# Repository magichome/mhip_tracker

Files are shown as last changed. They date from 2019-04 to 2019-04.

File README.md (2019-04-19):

# mhip_tracker

## Introduction

With my interest in IoT, the Internet-of-Things, I decided to create a device to addresses a use case I have, asset tracking.  Specifically I wanted a self-contained, solar powered GPS Tracker that periodically reports position to a cloud data store.  Primarily I'll use this to track by travels (I travel a lot in an RV).

This project will cover all aspects of the tracker device including hardware, software, packaging, and data visualization.

### Parts Used

- [Particle.io Boron](https://docs.particle.io/datasheets/cellular/boron-datasheet/)
  - An Arduino compatible controller with cellular connectivity.
- [Adafruit GPS FeatherWing](https://www.adafruit.com/product/3133)
  - -165 dBm sensitivity, 10 Hz updates, 66 channels with internal patch antenna
- [Adafruit Temperature/Humidity Sensor](https://www.adafruit.com/product/393)
  - wired DHT22 sensor in a plastic housing
- [Voltaic USB Battery Pack](https://www.voltaicsystems.com/v44)
  - Model V44, 12,000mAh / 44 Watt hour
- [Voltaic Solar Panel](https://www.voltaicsystems.com/9-watt-panel)
  - 9 watts, 6 volts, plugs directly into the V44 battery pack.
- Component case and solar panel mount
  - Custom 3D printed
- Double-sided tape, grommets, bolts and nuts

### Services Used

- [Particle.io Cloud](https://www.particle.io/)
- Microsoft Azure
  - [IOT Hub](https://azure.microsoft.com/en-us/services/iot-hub/)
  - [Event Grid](https://azure.microsoft.com/en-us/services/event-grid/)
  - [Table Storage](https://azure.microsoft.com/en-us/services/storage/tables/)

### Discussion

The "brains" of Tracker is the particle.io Boron controller board.  The Boron is Arduino compatible and in the Adafruit Feather [formfactor](https://learn.adafruit.com/adafruit-feather/feather-specification). In addition to the controller it has a cellular modem that communicates with the cellular network.  Depending on the model you choose, it can use either G2/G3 or LTE.  I chose G3 since it gives greater coverage compares to LTE.

The Boron includes a SIM that you activate with the particle.io mobile app running on either an [Android](https://play.google.com/store/apps/details?id=io.particle.android.app&hl=en_US) or the [iPhone](https://itunes.apple.com/us/app/particle-iot/id991459054).  Out of the box, Boron communicates with the particle.io cloud (at the time of this writing the particle.io cloud is free for the first three months then $2.99 per month per device).  With their cloud subscription you get 3MB of data per month. Additional megabytes start at $0.40/MB.  In addition to activating your Boron, the mobile app can be used to monitor and control your devices.

In addition to cellular connectivity, the particle.io devices can communicate with each other via a mesh network.  I plan to use the capability in future IoT projects to combine location data with other sensor data I collect.

The particle.io cloud is more than just a data hub for their products.  It is a centralized place to manage your devices as well as a Web IDE for writing and flashing code to your devices.

I've taken a couple stabs at creating an IoT controller with cellular connectivity.  This included a roll-my-own attempt using a RaspberryPi and the AT&T IoT developer board.  Those didn't work out.  I had run across particle.io but, at that time, their devices weren't ready.  Time passed before my latest attempt so I revisited their offerings.  It looked promising so I decided to give it a try.  I'm impressed.  Not only do they have good hardware, they're created an ecosystem around the hardware that makes IoT development easy.  Yes, easy.  I had my Boron registered and reporting status to the particle.io cloud within minutes of powering it up.  I breadboarded it with the GPS module, wrote some code with their [Web IDE][1], flashed it to the device (also through the Web IDE), and had it reporting location within just a couple hours.

Since the Boron is compatible with the Adafruit Feather specification, I looked (on [adafruit.com](https://adafruit.com) naturally) for a compatible GPS module.  I chose the [Adafruit GPS FeatherWing](https://www.adafruit.com/product/3133) because of its easy serial connectivity and integrated antenna.

The temperature/humidity sensor was added because, well, why not?  Temperature and humidity are interesting things to know, right?

Since I want the Tracker to be standalone, I needed to supply power.  Solar is an  obvious part of the solution.  The Boron has an integral charge controller and LiPo battery.  You could hook a solar panel to the Boron USB connection to power the device and charge the LiPo.  When there isn't enough solar, the LiPo can power the device.

Having dealt with solar powered devices for some time, I knew that powering the device this way would be problematic.  Solar panels rarely live up to their claimed power output in real world situations.  Dust accumulation on the panel, low sun angle, shade, clouds, all contribute to the challenge.  Since I intended to attach this to a vehicle, I can't optimize the angle of the panel or ensure that it will always be in locations with adequate sunlight[2][2].  My approach was to get the largest solar panel I could coupled with a hefty battery pack.  The large solar panel can charge the battery pack as quickly as possible and the battery pack can keep the device running for days without sun.  The [Voltaic USB Battery Pack](https://www.voltaicsystems.com/v44) I chose has a couple desirable features that are important for this application:

- The solar panel plugs directly into the battery pack.  The panel can charge the battery even while it's providing power to the device.  Many battery packs can't do this.
- Always on.  If the battery pack is fully drained, it will start providing power to the connected device as soon as an adequate level of charge is attained.
- Weatherproof

With all of the parts selected, I needed a way to package them.  Since Tracker will be exposed to the weather, the case needed some level of weather and UV resistance.  Since its going to be attached to a vehicle, it will encounter wind forces and foreign object impacts.  Specifically I was going to need a box to house the controller, GPS module and battery pack. I would also need a mount for the solar panel.  I couldn't find anything off the shelf.  Fortunately this need intersected with my growing interest in 3D printing.  And it provided the needed justification to buy a 3D printer!

[1]: If you're not a fan of Web IDE's, particle has a workbench extension for Visual Code so you can develop and compile locally.  See the [Software Section](doc/software.md) for more information.

[2]: Using solar power on vehicles, e.g. an RV, is challenging in itself.  The desire to keep the vehicle out of the sun to protect it (and keep it cool in the summer), is diametrically opposed to the needs of solar power.

### More Information

- [Hardware](doc/hardware.md)
- [Software](doc/software.md)
- [3D Printed Parts](doc/cad.md)
- Data Processing (coming...)
- Performance (coming...)

### Images

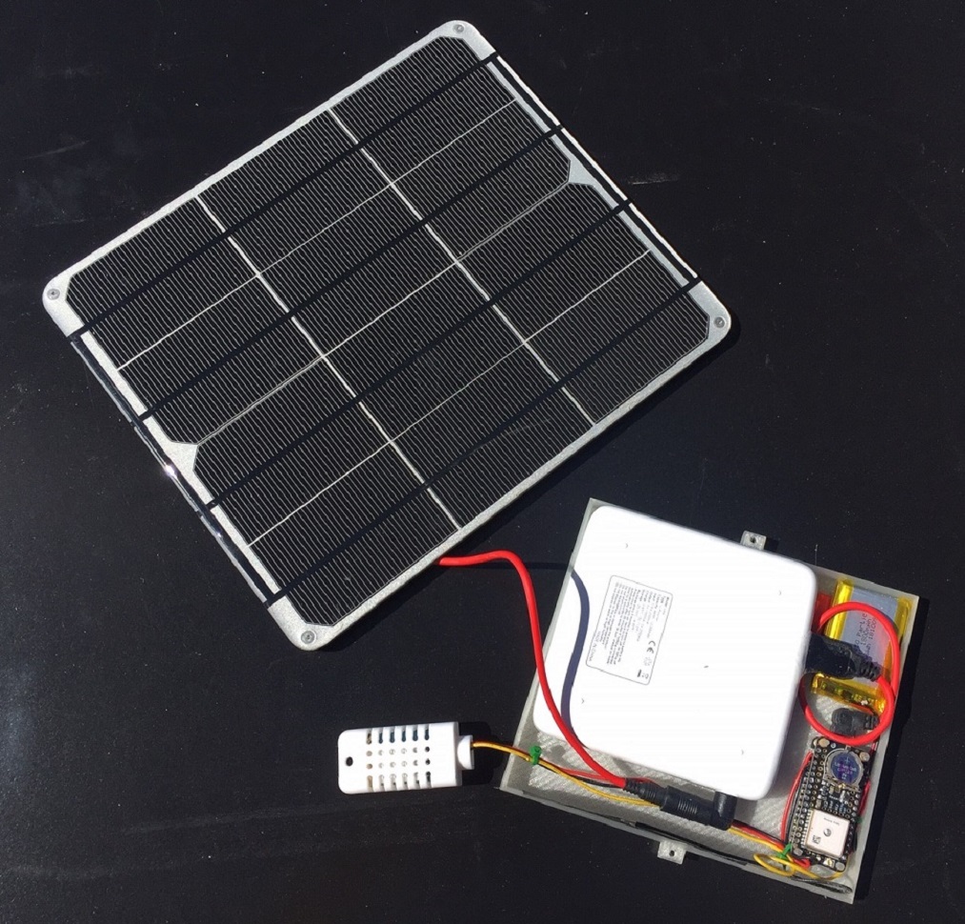
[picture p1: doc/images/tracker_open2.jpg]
Tracker Open View 2

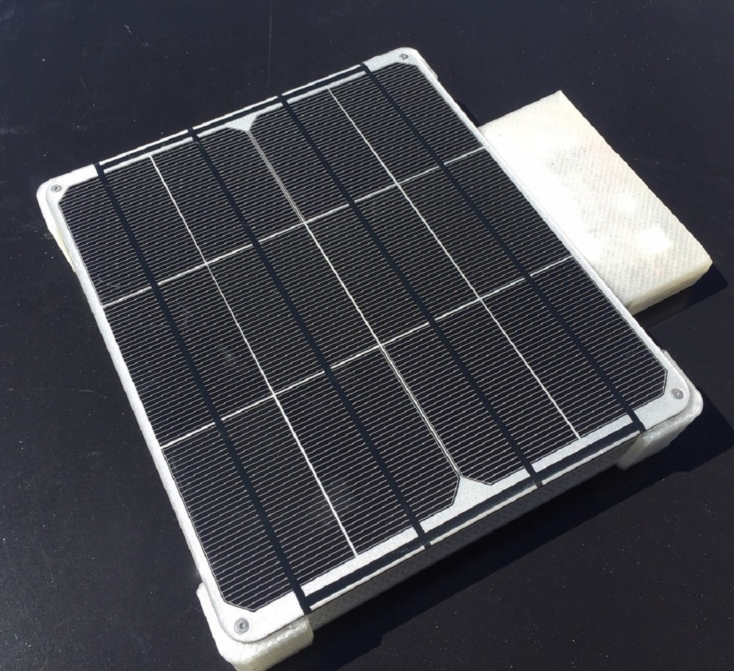
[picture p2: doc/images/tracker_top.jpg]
Tracker Top

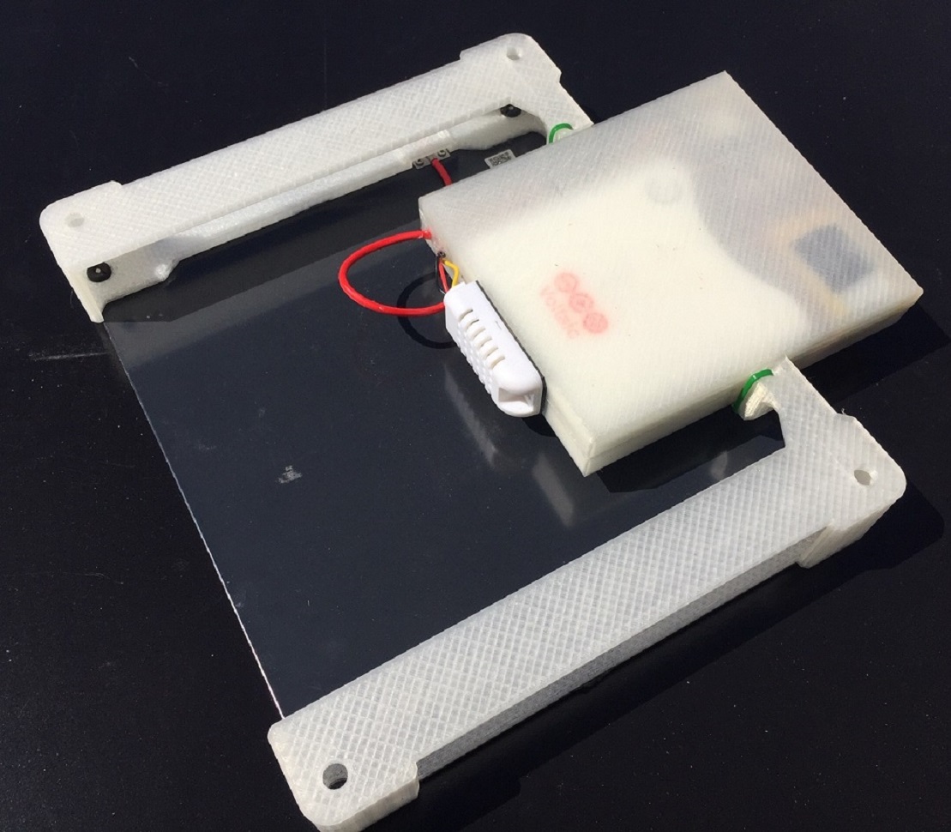
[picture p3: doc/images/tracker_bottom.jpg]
Tracker Bottom


### Note

I am not affiliated with any company or product mentioned in this project.  All products and services were chosen based on my own research and paid for my me.

### Licenses

Source Code: [MIT](https://opensource.org/licenses/MIT)

Text and Images: [Creative Commons Attribution-ShareAlike 3.0 Unported](https://creativecommons.org/licenses/by-sa/3.0/legalcode)

**Copyright 2019, MagicHome Inc., All rights reserved.**

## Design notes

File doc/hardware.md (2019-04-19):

# mhip_tracker : Hardware

## Parts Used

- [Particle.io Boron](https://docs.particle.io/datasheets/cellular/boron-datasheet/)
  - An Arduino compatible controller with cellular connectivity.

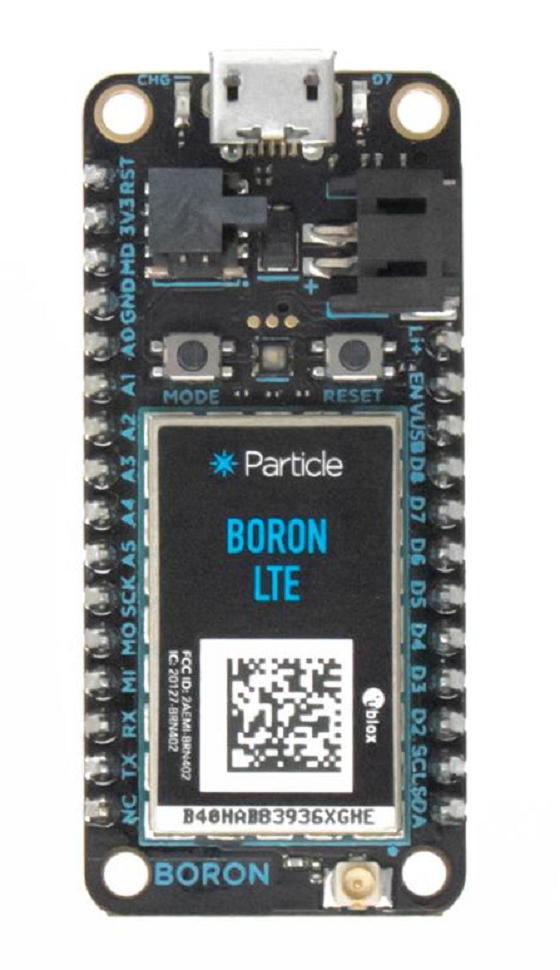
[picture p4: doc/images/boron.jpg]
particle.io Boron controller
    

- [Adafruit GPS FeatherWing](https://www.adafruit.com/product/3133)
  - -165 dBm sensitivity, 10 Hz updates, 66 channels with internal patch antenna

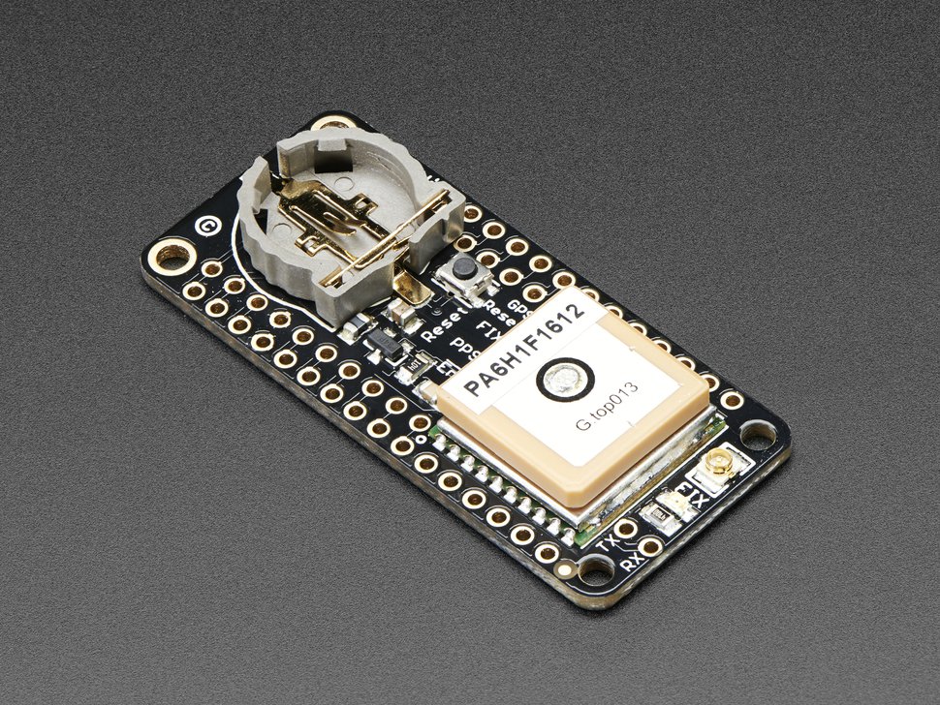
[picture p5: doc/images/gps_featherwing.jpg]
Adafruit GPS FeatherWing
    

- [Adafruit Temperature/Humidity Sensor](https://www.adafruit.com/product/393)
  - wired DHT22 sensor in a plastic housing

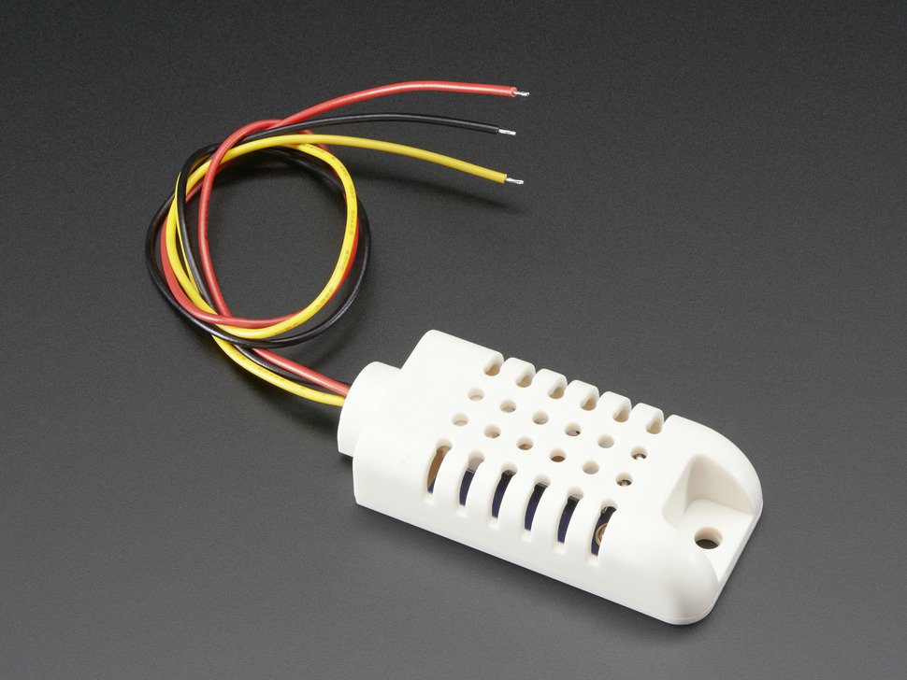
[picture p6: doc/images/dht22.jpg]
Adafruit Temperature and Humidity Sensor
    

- [Voltaic USB Battery Pack](https://www.voltaicsystems.com/v44)
  - Model V44, 12,000mAh / 44 Watt hour

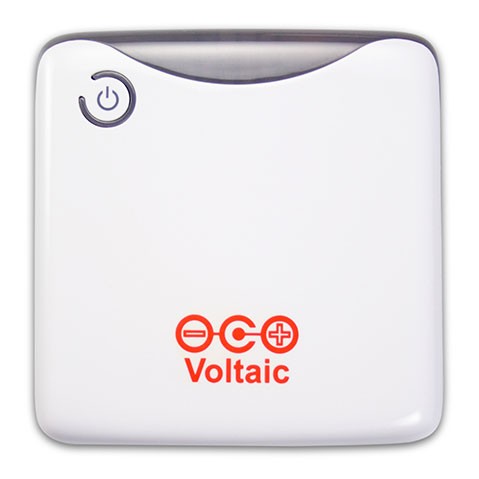
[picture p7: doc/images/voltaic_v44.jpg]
Voltaic V44 Battery Pack
    

- [Voltaic Solar Panel](https://www.voltaicsystems.com/9-watt-panel)
  - 9 watts, 6 volts, plugs directly into the V44 battery pack.

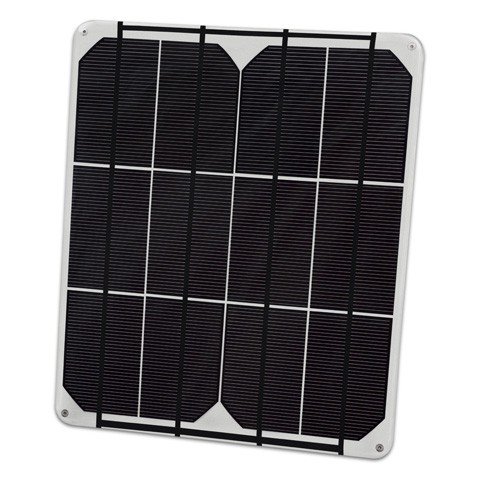
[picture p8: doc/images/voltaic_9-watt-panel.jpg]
Voltaic 9W Solar Panel
    

_todo: fritzing diagram, assembly_

**Copyright 2019, MagicHome Inc., All rights reserved.**

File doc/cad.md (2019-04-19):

# mhip_tracker : 3D Printed Parts

## Case and Solar Panel Mount

The ```cad``` folder has [SketchUp](https://www.sketchup.com/) and .STL files for the case (top and bottom) and solar panel mount.  These can be used to 3D print these components.

## Design Considerations

Packaging requirements:

- External mount
  - For solar power
  - Good gps singal reception
  - Good cellular connectivity.
- Self-contained
  - All of the parts together in a single package.

These requirements present several design considerations.  Since tracker is outside and moving with a vehicle, it is subject to hazards such as...

- Heat, rain, hail
- UV radiation
- Foreign object impact; e.g. rocks, tree limbs

Heat, rain, hail and UV radiation can be mitigated somewhat by keeping things shaded.  The solar panel cannot be shaded (obviously) but it is designed with the hazards in mind.  I can used the solar panel for shade it positioned off the vehicle enough.  Keep in mind though that solar panels get HOT.  So there would need to be good airflow around it so it doesn't transfer heat to the things it's shading.

Foreign object impacts are mitigated by keeping things as low profile as possible and designing them strong enough to handle incidental impacts.

## About the printer

I used the [Qidi X-Plus](http://www.qd3dprinter.com/products/x-plus/) printer.  I selected this printer based on reviews and max print size.  It has been very easy to use and reliable.  The slicing software seems a little less than smooth but it gets the job done.  The components are printed with generic PLA filament.  I chose translucent so I could see flashing lights on the components (for troubleshooting) without disassembly.

## Components

### Case

The case houses the Voltaic battery pack, the LiPo battery included with Boron, the Boron controller and the GPS board.  The battery pack being the largest of these.  I positioned the GPS board on top of the Boron so it's internal antenna would have an unobstructed view of the sky.  I positioned these toward one edge so I could position that side of the box exposed while the rest of the case could be in the shade under the solar panel.

### Solar Panel Mounts

These were designed to hold the panel up high enough to provide shade for the case.  In addition, they are somewhat minimal and open to improve airflow.  Finally, they fall along the short dimension of the panel to make them small enought to print in my 3D printer.

## Lessons Learned

Originally I had intended to mount the component case and solar panels separately.  I also intended to use heavy-duty double-sided tape to hold them to the vehicle.  I had already printed the cases with this in mind but quickly discovered the following...

_The box tabs are too small._

The tabs are too small to hold the case halves together.  For a "version 2" I would probably make these 2x larger and have four tabs, one along each side.

I also discovered that...

_The box warps as it cools, it won't lay flat._

This is a 3D printing thing for large, flat surfaces.  I think if I let it cool an the build platform it may stay flat.  In any case this means that using double-side tape to secure the case to the vehicle would be compromised since the contact surface area is reduced.

So while designing the solar mount brackets, I wanted to incorporate a way to tie the case to the brackets.  This would give a little extra force to keep it attached to the vehicle.

_The bracket "openings" for the box tabs are too tight._

3D print plastic expands a little during printing making holes and other clearances tighter than designed.  I allowed for this and it mostly worked out.  However, in this complex tab recepticle, it wasn't enough.  I took one shot at fixing the problem but still not enough.  The brackets take a long time to print so instead of fixing the design I just used a dremel tool to open them up a bit.

_It's probably a good idea to get the nuts, bolts, and screws you intend to use before designing._

I sized holes according to screws and bolts I assumed I could readily find.  I couldn't.  That's why I went with plastic pins on the circuit boards and cable ties for the case tabs.  I think the approach I took turned out fine but I would have designed things a little differently if I knew this ahead of time.

_The case should probably be rotated 90 degrees counterclockwise so both batteries would be shaded by the solar panel._

Oooh, better idea.  Rotate the case _45 degrees_ counterclockwise!  That way only the corner with the GPS antenna needs to be outside the shade of the solar panel.  In addition the distance between the case and the solar panel mounts is reduced making for a more robust connection.  Finally, having the case angled to the vehicle motion would reduce the force of foreign object impacts.

## Closing Remarks

I've already printed all of the components I need for my application so I won't be spending any time right now to improve them.  If anyone would like to make improvements or offer alternative packaging and mounting designs, just give me a pull request.

**Copyright 2019, MagicHome Inc., All rights reserved.**

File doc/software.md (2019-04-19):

# mhip_tracker : Software

The particle.io Boron is an Arduino controller and programmed similarly.  The quickest and easiest way to program your Boron is via the particle.io Web IDE.  Once you register your device and create an account on particle.io, you will be able to navigate to the online [console](https://console.particle.io) where you can access your device, write code, and flash your device.  Simply copy the content of the src/mhip_tracker.ino file into the Web IDE.  Buttons on the left margin of the IDE let you compile and flash your device.

Alternatively you can use [Visual Code](https://code.visualstudio.com/) editor with the [Particle Workbench](https://www.particle.io/workbench/) extension.  If you don't already have Visual Code installed, the Particle Workbench link will give you the opportunity to install it with the extension pre-installed.  Otherwise, if you do have Visual Code, you can install the extension via the Visual Code marketplace.

Note that this code was written and tested on deviceOS 0.9.0.

(The information below is generic particle.io development documentation.)

## Development

Particle projects are composed of 3 important elements:

### ```/src``` folder:

This is the source folder that contains the firmware files for your project. It should *not* be renamed. 
Anything that is in this folder when you compile your project will be sent to our compile service and compiled into a firmware binary for the Particle device that you have targeted.

If your application contains multiple files, they should all be included in the `src` folder. If your firmware depends on Particle libraries, those dependencies are specified in the `project.properties` file referenced below.

### ```.ino``` file:

This file is the firmware that will run as the primary application on your Particle device. It contains a `setup()` and `loop()` function, and can be written in Wiring or C/C++. For more information about using the Particle firmware API to create firmware for your Particle device, refer to the [Firmware Reference](https://docs.particle.io/reference/firmware/) section of the Particle documentation.

### ```project.properties``` file:

This is the file that specifies the name and version number of the libraries that your project depends on. Dependencies are added automatically to your `project.properties` file when you add a library to a project using the `particle library add` command in the CLI or add a library in the Desktop IDE.

## Adding additional files to your project

### Projects with multiple sources

If you would like add additional files to your application, they should be added to the `/src` folder. All files in the `/src` folder will be sent to the Particle Cloud to produce a compiled binary.

### Projects with external libraries

If your project includes a library that has not been registered in the Particle libraries system, you should create a new folder named `/lib/<libraryname>/src` under `/<project dir>` and add the `.h`, `.cpp` & `library.properties` files for your library there. Read the [Firmware Libraries guide](https://docs.particle.io/guide/tools-and-features/libraries/) for more details on how to develop libraries. Note that all contents of the `/lib` folder and subfolders will also be sent to the Cloud for compilation.

## Compiling your project

When you're ready to compile your project, make sure you have the correct Particle device target selected and run `particle compile <platform>` in the CLI or click the Compile button in the Desktop IDE. The following files in your project folder will be sent to the compile service:

- Everything in the `/src` folder, including your `.ino` application file
- The `project.properties` file for your project
- Any libraries stored under `lib/<libraryname>/src`

**Copyright 2019, MagicHome Inc., All rights reserved.**

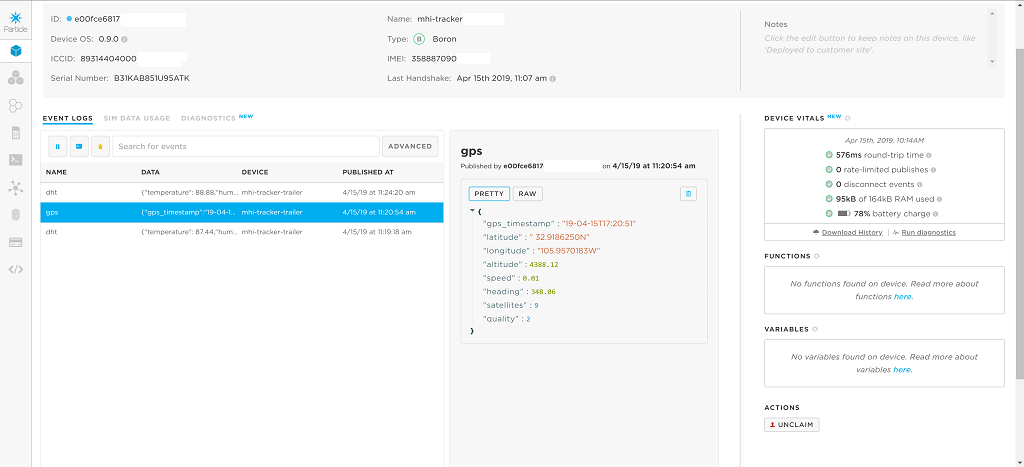
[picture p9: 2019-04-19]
doc/images/mhi_tracker_gps.png

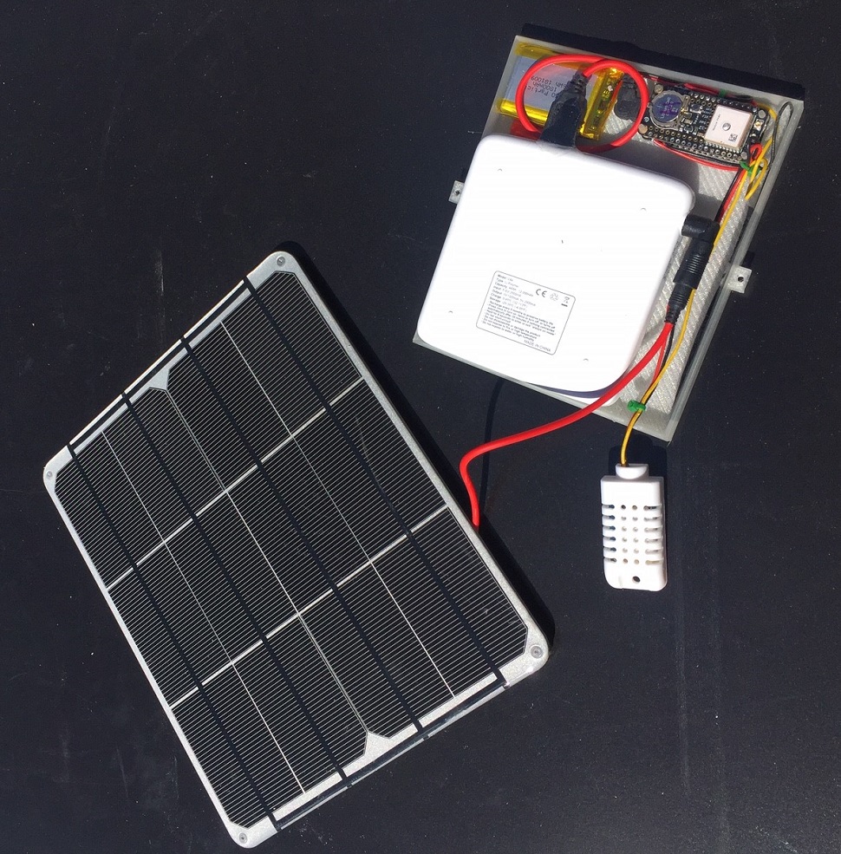
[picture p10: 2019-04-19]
doc/images/tracker_open1.jpg

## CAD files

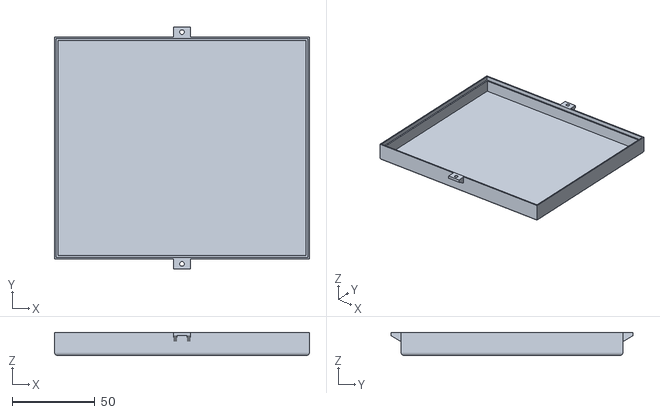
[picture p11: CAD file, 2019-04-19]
cad/miota_tracker_case_top.stl
154.0 x 146.0 x 14.0

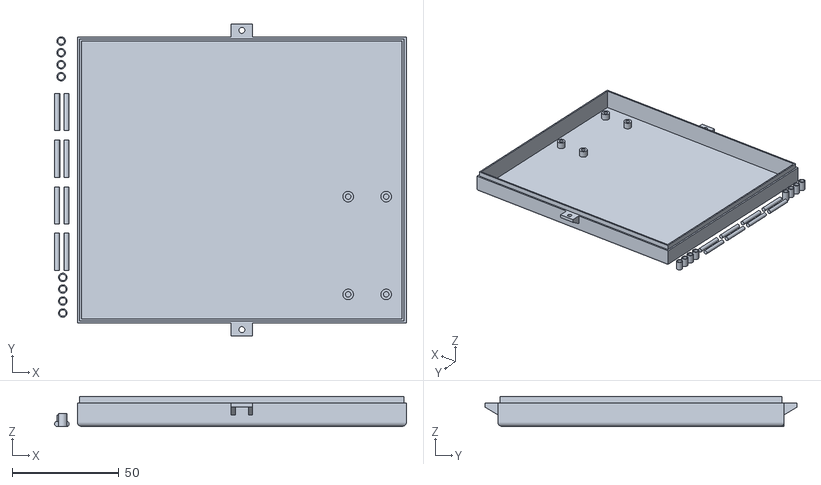
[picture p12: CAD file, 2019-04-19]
cad/miota_tracker_case_bottom.stl
164.7 x 146.0 x 14.1

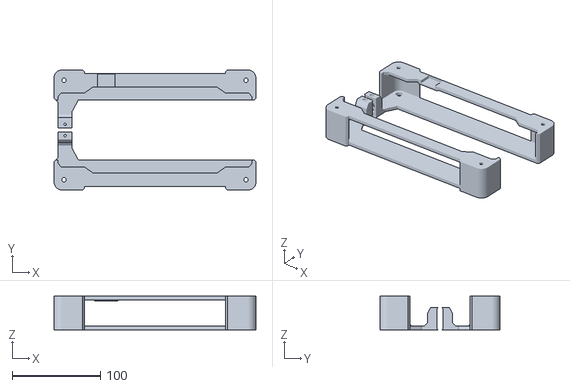
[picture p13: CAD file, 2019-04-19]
cad/miota_tracker_solar_mount.stl
229.1 x 136.2 x 38.0

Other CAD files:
cad/miota_tracker_case_bottom.skp
cad/miota_tracker_case_top.skp
cad/miota_tracker_solar_mount.skp

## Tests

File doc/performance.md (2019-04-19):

# mhip_tracker : Performance

## Batteries

- With fully charged batteries, tracker worked for 5+ days without charging.  
- Once the batteries were depleted, tracker started working again after x hours in decent sunlight.

## GPS

- Outstanding.

## DHT

- Temperature goes rogue occassionally.  When it's right, it's pretty accurate.  But sometimes it gives a reading about 50% higher than actual.  I'm attempting to do some validation on the temperature readings and only report those that seem accurate but the algorithm needs more work.

## Celluar Connectivity

- TBD

## Cost

### Components

### Services

**Copyright 2019, MagicHome Inc., All rights reserved.**

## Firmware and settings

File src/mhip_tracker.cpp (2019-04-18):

#include "application.h"
#line 1 "c:/Users/timjf/workspace/miota/mhip_tracker/src/mhip_tracker.ino"
/*
 * Project:     mhip_tracker
 * Description: GPS tracker using 2G/3G communication.
 * Author:      Timothy Fleming, MagicHome Inc
 * Date:        2019-03-24
 * Copyright:   MIT (see: https://opensource.org/licenses/MIT)
 */

#include <Adafruit_GPS.h>
#include <Adafruit_DHT.h>

void setupGPS();
void loopGPS();
int32_t calcCloudUpdateInterval(int32_t speed);
void setupDHT();
void loopDHT();
boolean validateTempurature(float t, float h);
void setup();
void loop();
#line 12 "c:/Users/timjf/workspace/miota/mhip_tracker/src/mhip_tracker.ino"
#define DHTPIN 3     // Digital pin connected to the DHT sensor 

// Uncomment the type of sensor in use:
//#define DHTTYPE    DHT11     // DHT 11
#define DHTTYPE    DHT22     // DHT 22 (AM2302)
//#define DHTTYPE    DHT21     // DHT 21 (AM2301)

// See guide for details on sensor wiring and usage:
//   https://learn.adafruit.com/dht/overview
DHT dht(DHTPIN, DHTTYPE);

// what's the name of the hardware serial port?
#define GPSSerial Serial1

// Connect to the GPS on the hardware port
Adafruit_GPS GPS(&GPSSerial);

// these are the intervals for when events get sent
// GPS cloud interval varies depending on speed; faster -> more frequent updates
uint32_t TI_GPS_CLOUD_MIN = 20 * 60 * 1000;   // 20 min, interval when we're stationary
uint32_t TI_GPS_CLOUD_MAX =  1 * 60 * 1000;   //  1 min, interval when we're moving fast
uint32_t TI_DHT_CLOUD     = 10 * 60 * 1000;   // 10 min
// MESH updates are all the same.  Sensors are read at this rate.
uint32_t TI_ALL_MESH      = 2000;             //  2 sec

// these are appended to the device name to create event names
#define EVENT_NAME_LOCATION "gps"
#define EVENT_NAME_TEMP "dht"

// init timer counts
uint32_t timer_gps_cloud = TI_GPS_CLOUD_MIN;
uint32_t timer_dht_cloud = TI_DHT_CLOUD;
uint32_t timer_mesh = 1000;

// these are used to apply some quality control to temp values
float t_last;
uint16_t t_count;

// message buffers
char msg_gps [250];
char msg_dht [120];

// ============================================================================
// GPS : Location Functions 
// ============================================================================

// Configure GPS board
void setupGPS() {
  Serial.println("GPS : setup");

  // This defines a variable with the particle cloud.  It enables us to query the value any time.
  Particle.variable("gps", msg_gps, STRING);

  // Note: the following code/comments are pasted from the Adafruit example code.  I don't actually know this
  // much about the GPS module.

  // 9600 NMEA is the default baud rate for Adafruit MTK GPS's- some use 4800
  GPS.begin(9600);
  // uncomment this line to turn on RMC (recommended minimum) and GGA (fix data) including altitude
  GPS.sendCommand(PMTK_SET_NMEA_OUTPUT_RMCGGA);
  // uncomment this line to turn on only the "minimum recommended" data
  //GPS.sendCommand(PMTK_SET_NMEA_OUTPUT_RMCONLY);
  // For parsing data, we don't suggest using anything but either RMC only or RMC+GGA since
  // the parser doesn't care about other sentences at this time
  // Set the update rate
  GPS.sendCommand(PMTK_SET_NMEA_UPDATE_1HZ); // 1 Hz update rate
  // For the parsing code to work nicely and have time to sort thru the data, and
  // print it out we don't suggest using anything higher than 1 Hz

  // Request updates on antenna status, comment out to keep quiet
  GPS.sendCommand(PGCMD_ANTENNA);

  delay(1000);

  // Ask for firmware version
  GPSSerial.println(PMTK_Q_RELEASE);
}

// GPS processing in main loop
void loopGPS() {
  // location formatting
  int32_t lat_units = GPS.latitude_fixed / 10000000;
  int32_t lat_decimal = GPS.latitude_fixed - (lat_units * 10000000);

  int32_t lon_units = GPS.longitude_fixed / 10000000;
  int32_t lon_decimal = GPS.longitude_fixed - (lon_units * 10000000);

  // unit conversions
  float speed_mph = GPS.speed * 1.15078;
  float alt_ft = GPS.altitude * 3.28084;

  // Format GPS message as json
  // Example: {"gps_timestamp":"19-03-26T20:04:33","latitude":" 39.7766033N","longitude":"105.1291466W","altitude": 5416.01,"speed":  0.17,"heading":257.14,"satellites":11,"quality":2}
  snprintf(msg_gps, 250, "{\"gps_timestamp\":\"%u-%02u-%02uT%02u:%02u:%02u\",\"latitude\":\"%3lu.%7lu%c\",\"longitude\":\"%3lu.%7lu%c\",\"altitude\":%8.2f,\"speed\":%6.2f,\"heading\":%6.2f,\"satellites\":%u,\"quality\":%u}", \
    GPS.year, GPS.month, GPS.day, GPS.hour, GPS.minute, GPS.seconds, \
    lat_units, lat_decimal, GPS.lat, \
    lon_units, lon_decimal, GPS.lon, \
    alt_ft, speed_mph, GPS.angle, GPS.satellites, GPS.fixquality);

  // output to console
  Serial.print("GPS: "); Serial.print(msg_gps);

  // mesh publish
  Mesh.publish(EVENT_NAME_LOCATION, msg_gps);

  // particle.io cloud publish, cloud interval is longer than mesh interval
  uint32_t dynamic_timer_interval = calcCloudUpdateInterval(speed_mph);
  if (millis() - timer_gps_cloud > dynamic_timer_interval) {
    timer_gps_cloud = millis(); // reset the timer
    Serial.print("*"); // give indication on console value that this one was published to cloud
    Particle.publish(EVENT_NAME_LOCATION, msg_gps, PRIVATE);
  }
  Serial.println("");
}

// The cloud update interval varies depending on speed.  Calculate the desired interval given the current speed.
int32_t calcCloudUpdateInterval(int32_t speed) 
{
  int32_t result = TI_GPS_CLOUD_MIN;

  if ( speed > 60 )
  {
    result = TI_GPS_CLOUD_MAX;
  } 
  else if ( speed > 2 )
  {
    result = (60 / speed) * TI_GPS_CLOUD_MAX;
  }

  return result;
}


// ============================================================================
// DHT : Temperature / Humidity Functions 
// ============================================================================

// Configure DHT temp/humidity sensor
void setupDHT() {
  // Initialize device.
  Serial.println("DHT : setup");

  // This defines a variable with the particle cloud.  It enables us to query the value any time.
  Particle.variable("dht", msg_dht, STRING);

  dht.begin();
}

// Temp/humidity sensor processing in main loop.
void loopDHT() {
  // read value from sensor
  float t = dht.getTempFarenheit();   // temp, F
  float h = dht.getHumidity();        // humidity, %
  
  // Check if any reads failed and exit early (to try again).
  if ( !validateTempurature(t,h) ) {
    return;
  }

  // these are read as degrees C, convert to F.
  float hi = dht.getHeatIndex() * 1.8 + 32; // heat index, F
  float dp = dht.getDewPoint() * 1.8 + 32;  // dew point, F

  // format temp/humidity message as json
  // Example: {"temperature": 70.16,"humidity": 24.00,"dew_point": 31.68,"heat_index": 75.12}
  snprintf(msg_dht, 120, "{\"temperature\":%6.2f,\"humidity\":%6.2f,\"dew_point\":%6.2f,\"heat_index\":%6.2f}", t, h, dp, hi);

  // output to serial console
  Serial.print("DHT: "); Serial.println(msg_dht);
 
  // publish to mesh network
  Mesh.publish(EVENT_NAME_TEMP, msg_dht);
  
  // publish to particle.io cloud
  if (millis() - timer_dht_cloud > TI_DHT_CLOUD) {
    // reset timer
    timer_dht_cloud = millis(); // reset the timer
    // publish dht data
    Particle.publish(EVENT_NAME_TEMP, msg_dht, PRIVATE);
  }
}

// Sometimes the DHT will output wildly inaccurate temperatures.  If the current temp differs 
// by over 25% from the last value, we'll consider it invalid.  We'll retry the temp '5' times 
// before reporting the (possibly) invalid temp.  Because, after all, the Tracker  could be 
// on fire and the temp is valid.
boolean validateTempurature(float t, float h) {
  // the two checks below are never valid so we count the retrys
  if (isnan(h) || isnan(t)) {
    Serial.println("DHT : failed to read");
    return false;
  }

  if ( t > 200 || t < -200 ) {
    Serial.println("DHT : invalid temperature");
    return false;
  }

  // if we still have reties left to give, and the temp is out of range by some 25%
  // do a retry
  if ( t_count < 5 && (t < t_last * 0.75 || t > t_last * 1.25) ) {
    t_count = t_count + 1;
    return false;
  }

  // valid temp, reset
  t_count = 0;
  t_last = t;

  return true;
}


// ============================================================================
// Setup
// ============================================================================

// setup() runs once, when the device is first turned on.
void setup() {
  // connect at 115200 so we can read the GPS fast enough and echo without dropping chars
  // also spit it out
  Serial.begin(115200);
  Serial.println("MIot Tracker");

  setupGPS();
  setupDHT();
}


// ============================================================================
// Loop
// ============================================================================

// loop() runs over and over again, as quickly as it can execute.
void loop() {
  // fix timer wrap arounds
  if (timer_gps_cloud > millis()) timer_gps_cloud = millis();
  if (timer_dht_cloud > millis()) timer_dht_cloud = millis();
  if (timer_mesh > millis()) timer_mesh = millis();

  // read location
  // NB: while it would make more sense to do this in the loopGPS() function, it doesn't work there.
  //  Apparently the GPS.read() function needs to happen very often to get valid data.  
  //  It may have something to do with the "not listening" warning below. Not sure.
  GPS.read();

  bool validGPS = true;

  // if a sentence is received, we can check the checksum, parse it...
  if ( GPS.newNMEAreceived() ) {
    // a tricky thing here is if we print the NMEA sentence, or data
    // we end up not listening and catching other sentences!
    // so be very wary if using OUTPUT_ALLDATA and trytng to print out data
    if ( !GPS.parse(GPS.lastNMEA()) ) {
      // if we fail to parse a sentence we will wait for another
      // NB: I wouldn't print this to the console because it happens A LOT.
      validGPS = false; 
    }

    // if no fix, don't process
    if ( !GPS.fix ) {
      Serial.println("GPS : no fix");
      validGPS = false;
    }
  }

  if (millis() - timer_mesh > TI_ALL_MESH) {
    // process sensor data
    if ( validGPS ) {
      loopGPS();
    }
    loopDHT();
  }
}
